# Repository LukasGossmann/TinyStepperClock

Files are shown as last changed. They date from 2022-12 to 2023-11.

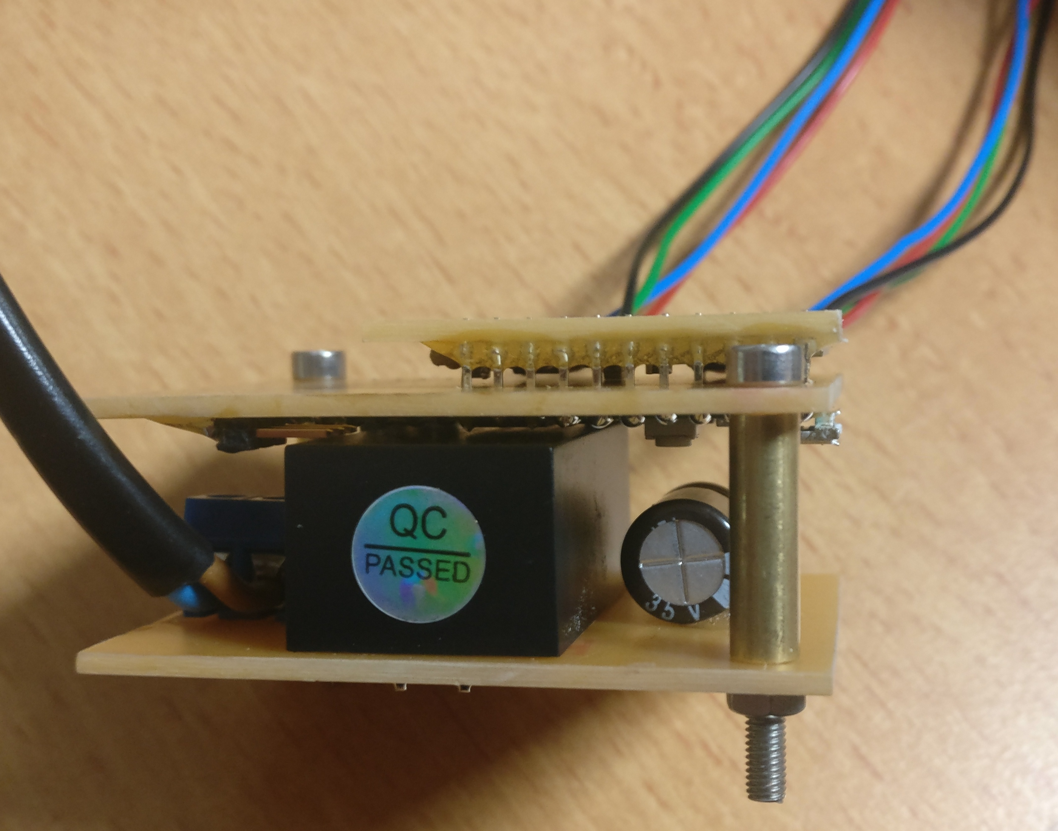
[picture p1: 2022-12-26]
Pictures/Complete_stack.png

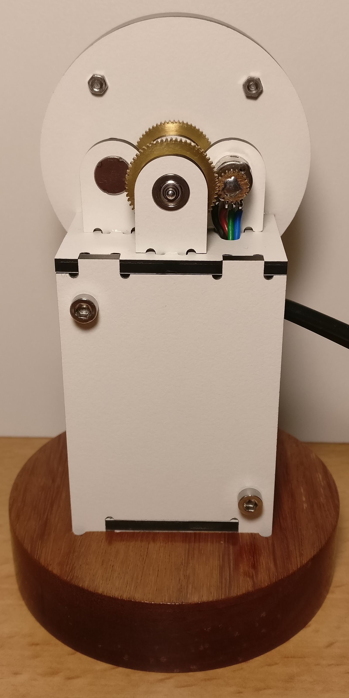
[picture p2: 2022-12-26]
Pictures/Back.png

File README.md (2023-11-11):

<p align="center">
Front view of the clock
</p>

**Description:**  
Tiny stepper motor based clock (including base, L=80mm, W=80mm, H=127mm)  
The clock face is 50mm in diameter with a 5mm wide clear / slightly opaque ring around it for a total diameter of 60mm.  
Behind the clock face is an LED ring with 12 WS2812 LEDs that light up every hour and play a short animation.  
The stepper motors used in this clock are very weak so a lot of care need to be taken to align the shafts properly and for the gears to be running as true as possible on the shafts.  
Each stepper motor has 20 fullsteps per revolution which with a gear reduction of 3:1 gives 60 steps per revolution.  
The minute hand takes a step every minute while the hour hand takes a step every 12 minutes.  
Since this is the tiny version that implies the existence of a bigger stepper motor based clock.
The bigger version can be found here: [StepperClock](https://github.com/LukasGossmann/StepperClock)  
**Waring:** The clock is mains powered and there are a few somewhat exposed live traces / metal contacts so build and use at your own risk.

**Building:**  
Create all parts needed as shown in the FreeCAD drawing.  
Assemble as shown on the pictures and in the FreeCAD drawing.  
A lot of care needs to be taken to be as precise as possible as there isn't much room for tolerance in this design due to the weak motors and tiny gears.  
Also a lot of parts are press fit together (bearings in holders, motors in holders, clock face in clear ring, clear ring on LED ring, etc.) so make sure to adjust the design to fit the expacted tolerances of your manufacturing process and the parts you bought.
Note that one of the stepper motors is wired in the opposite direction so that the same step sequence can be used to drive them.  
If the motors are turning in the wrong direction or both motors were wired the same on accident the code allows for inverting the motor direction as well.
When attaching the clock hands to the shaft the clock needs to be powered on (preferably through usb).  
That way the stepper motors align with one of their magnetic steps which ensures that the hands can properly point to all positions they need to.
Align the clock hands with the 12 o'clock position and solder them in place.

**Tools:**
- **CNC machine** or other way to create parts from a piece of flat material as well as for engraving the clock face.
- **FDM or SLA printer** to create the spacer and the clear ring.
- Depending on the parts you can get and the need to modify them a **lathe** is very useful.
- Soldering iron, screwdrivers, etc.

**Stepper motors:**  
20 steps per rev  
3.3V @ 80mA per coil (gets slightly warm)  
Does not like having both coils energized at the same time, gets pretty hot and doesn't step well  
Diameter: 8mm  
Length: 9.2mm  
Gear (from factory): 10 teeth 0.2 module? (2.3mm diameter)  
Can be found from multiple sellers in china for very cheap (AliExpress)

**Stepper driver:**  
DRV8833 without current limiting (3.3V straight through)  
On a breakout board just soldered onto carrier PCB

**Clock hands:**  
Need to be made of a material that can be soldered to so they can be attached to the shafts.  
CNC milling them from some leftover PCB material works great.

**Power supply:**  
The Pi Pico is powered from a 230V to 5V mains power supply "brick" made by Hi-Link which can supply 600mA.  
To power the stepper drivers the 3.3V output of the Pi Pico is used. 
The stepper motors together draw around 160mA at 3.3V with only one of their coils being active at a time.

**Needed parts (mechanical):**
- 2x 60 tooth gear, 1.4mm thick, 0.3 module
    - one with 4mm hole and one with 2mm hole for the shaft
- 2x 20 tooth gear, 1.4mm thick, 0.3 module
    - with 2.3mm hole to fit onto factory gear of the stepper motor
- 2x Bearing 8mm OD, 4mm ID, 3mm thick
- 1x Bearing 7.3mm OD, 2mm ID, 3mm thick
    - 7mm OD bearings are also available, pick whatever is cheaper and modify the bearing holder design to fit your needs
- 3mm thick material for the frame parts (I used Resopal)
- Brass tube 4mm OD, 2mm ID (shaft for the hour hand)
- Brass tube 5mm OD, 3mm ID (used as spacers for the stacked PCBs)
- Brass rod 2mm (shaft for the minute hand)
- Various M2 and M3 screws, nuts and washers
- A block of wood or other material to make a base for the clock

**Needed parts (electrical):**
- 2x Stepper motor
    - order more than that because they tend to arrive broken (coil wires ripped off)
- 1x Raspberry Pi Pico without headers
- 1x 5V PSU (Hi-Link HLK-PM01 or pin and size compatible)
- 1x WS2812 LED ring with 12 LEDS (~50mm OD)
    - 8 LED version (~32mm OD) should work too with a modified spacer and a few code changes
- 1x Diode (shotkey or any other type, 1N4007 works just fine)
- 1x Capacitor (At least 5V rating, around 470µF works fine)
- 1x 2.54mm 2 pin screw terminal
- Some 2.54mm pin headers
- Thin wires
- The PCBs from the KiCAD project

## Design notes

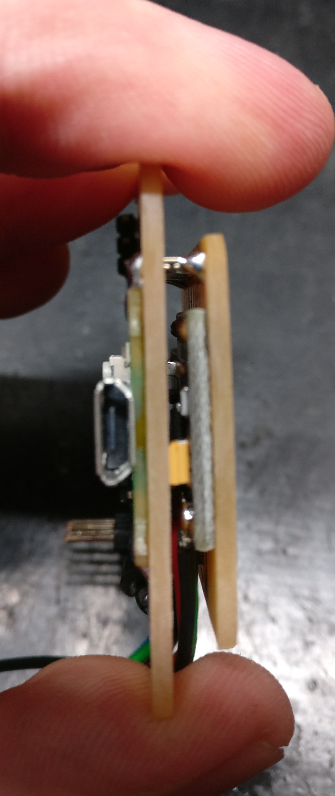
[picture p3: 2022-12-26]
Pictures/Pico_Stepper_driver_stack.png

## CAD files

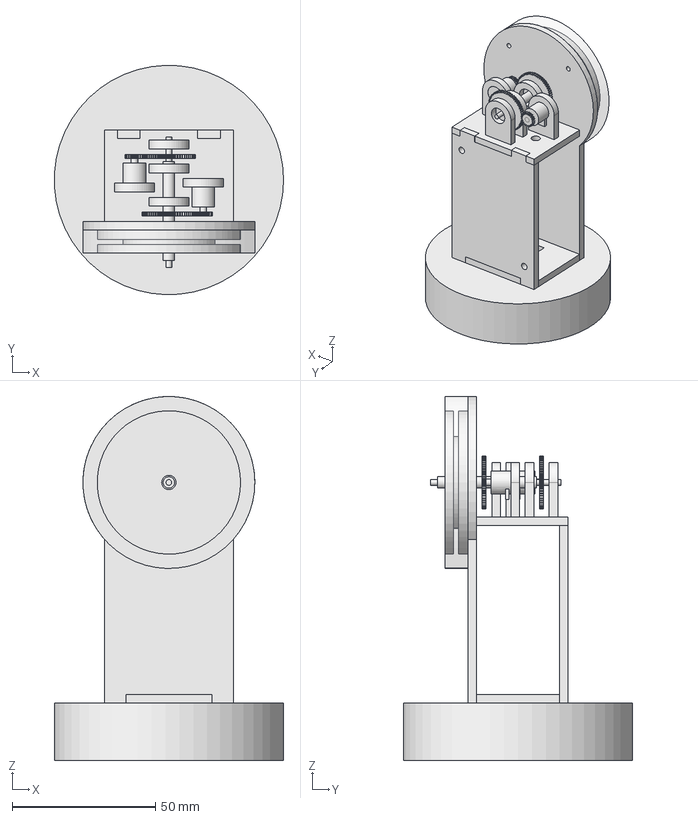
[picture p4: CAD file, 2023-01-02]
FreeCAD/TinyStepperClock.FCStd
79.9 x 80.0 x 127.0 mm
MinuteShaft
HourShaft
MinuteGear
HourGear
HourMotor
MinuteMotor
HourMotorHolder
MinuteMotorHolder
MinuteShaftBearingHolder
HourShaftFrontBearingHolder
HourShaftBackBearingHolder
BasePlate
DialPlate
FrontPlate
BackPlate
BottomPlate
ClearRing
LedRing
Spacer
StandPlate

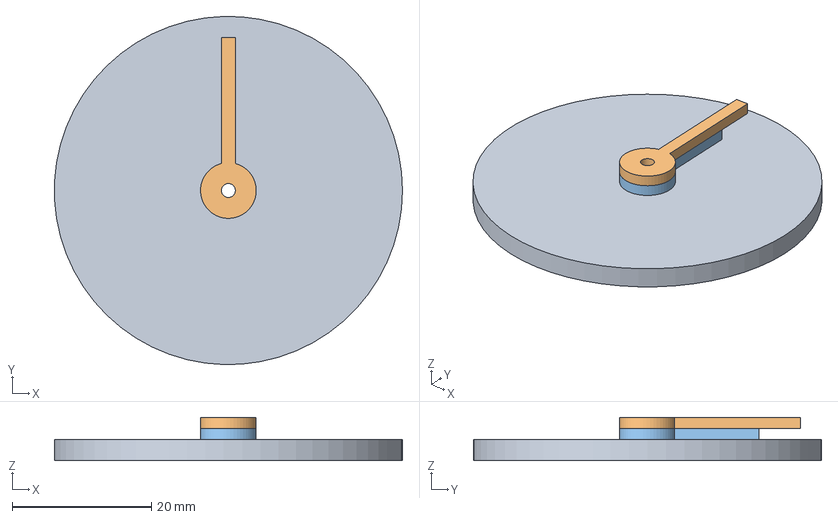
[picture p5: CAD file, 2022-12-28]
FreeCAD/ClockFace.FCStd
50.0 x 50.0 x 6.20 mm
DialPlate
MinuteHand
HourHand

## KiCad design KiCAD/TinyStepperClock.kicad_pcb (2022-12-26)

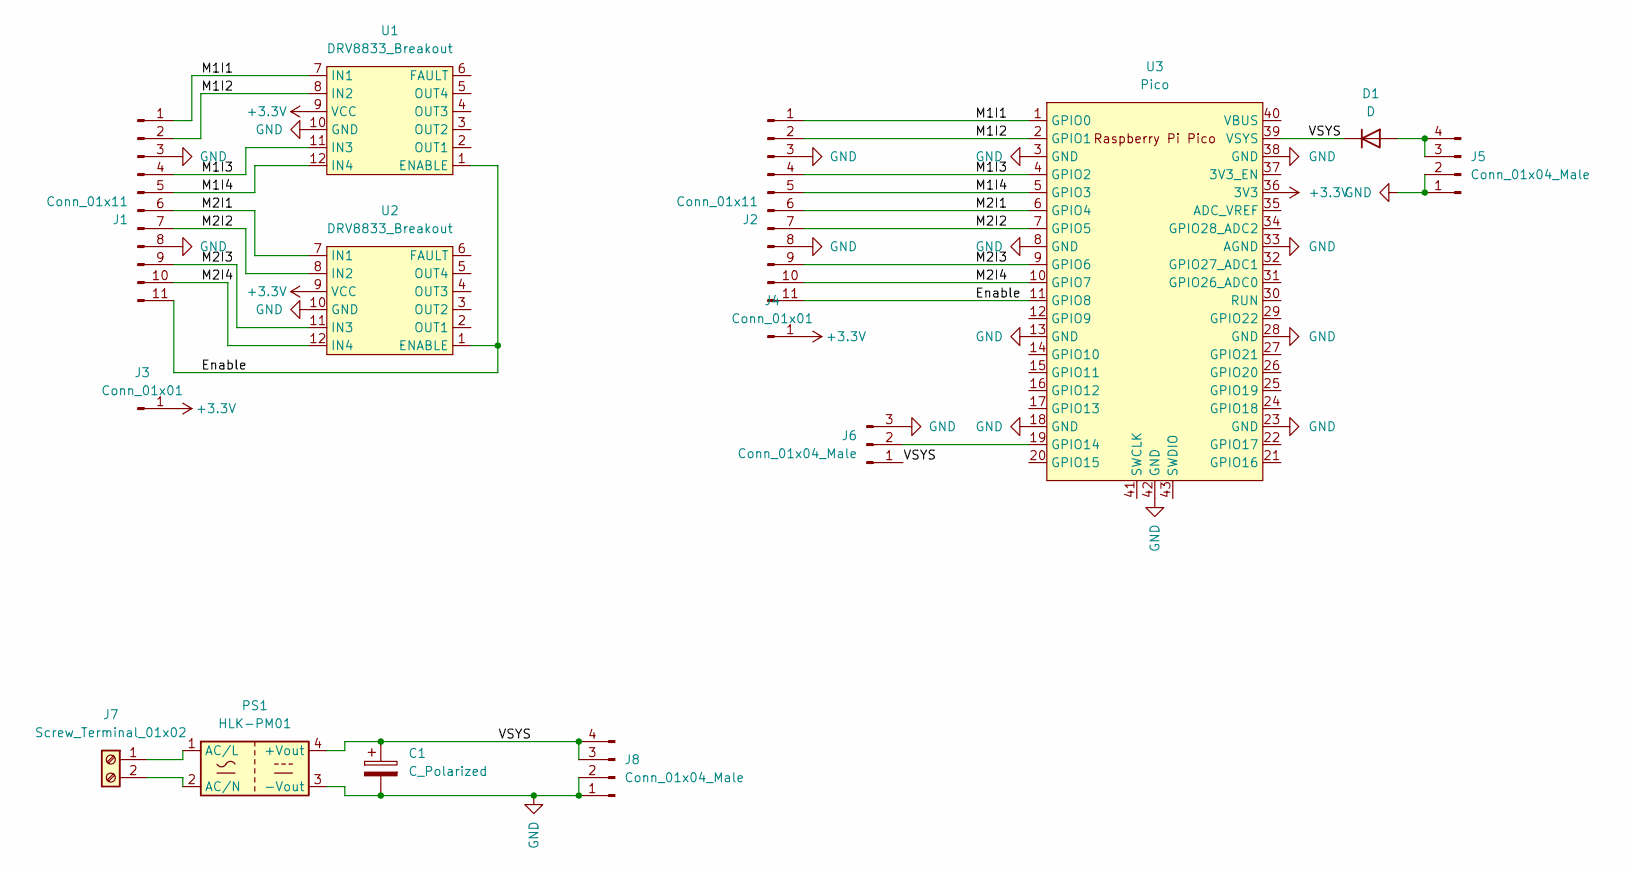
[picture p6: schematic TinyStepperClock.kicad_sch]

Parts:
C1: C_Polarized; CP_Radial_D10.0mm_P5.00mm_P7.50mm
D1: D; D_DO-15_P12.70mm_Horizontal
J1, J2: Conn_01x11; PinHeader_1x11_P2.54mm_Vertical
J3, J4: Conn_01x01; PinHeader_1x01_P2.54mm_Vertical
J5: Conn_01x04_Male; PinHeader_1x04_P2.54mm_Vertical
J6: Conn_01x04_Male; PinHeader_1x03_P2.54mm_Horizontal
J7: Screw_Terminal_01x02; TerminalBlock_Phoenix_MKDS-1,5-2-5.08_1x02_P5.08mm_Horizont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
J8: Conn_01x04_Male; PinSocket_1x04_P2.54mm_Vertical
PS1: HLK-PM01; Converter_ACDC_HiLink_HLK-PMxx
U1, U2: DRV8833_Breakout
U3: Pico; RPi_Pico_SMD_TH

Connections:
+3.3V: J3.1, J4.1, U1.9 (VCC), U2.9 (VCC), U3.36 (3V3)
/Enable: J1.11, J2.11, U1.1 (ENABLE), U2.1 (ENABLE), U3.11 (GPIO8)
/M1I1: J1.1, J2.1, U1.7 (IN1), U3.1 (GPIO0)
/M1I2: J1.2, J2.2, U1.8 (IN2), U3.2 (GPIO1)
/M1I3: J1.4, J2.4, U1.11 (IN3), U3.4 (GPIO2)
/M1I4: J1.5, J2.5, U1.12 (IN4), U3.5 (GPIO3)
/M2I1: J1.6, J2.6, U2.7 (IN1), U3.6 (GPIO4)
/M2I2: J1.7, J2.7, U2.8 (IN2), U3.7 (GPIO5)
/M2I3: J1.9, J2.9, U2.11 (IN3), U3.9 (GPIO6)
/M2I4: J1.10, J2.10, U2.12 (IN4), U3.10 (GPIO7)
/VSYS: C1.1, D1.1 (K), J6.1, J8.3, J8.4, PS1.4 (+Vout), U3.39 (VSYS)
GND: C1.2, J1.3, J1.8, J2.3, J2.8, J5.1, J5.2, J6.3, J8.1, J8.2, PS1.3 (-Vout), U1.10 (GND), U2.10 (GND), U3.3 (GND), U3.8 (GND), U3.13 (GND), U3.18 (GND), U3.23 (GND), U3.28 (GND), U3.33 (AGND), U3.38 (GND), U3.42 (GND)
unnamed: D1.2 (A), J5.3, J5.4
unnamed: J6.2, U3.19 (GPIO14)
unnamed: J7.1, PS1.1 (AC/L)
unnamed: J7.2, PS1.2 (AC/N)

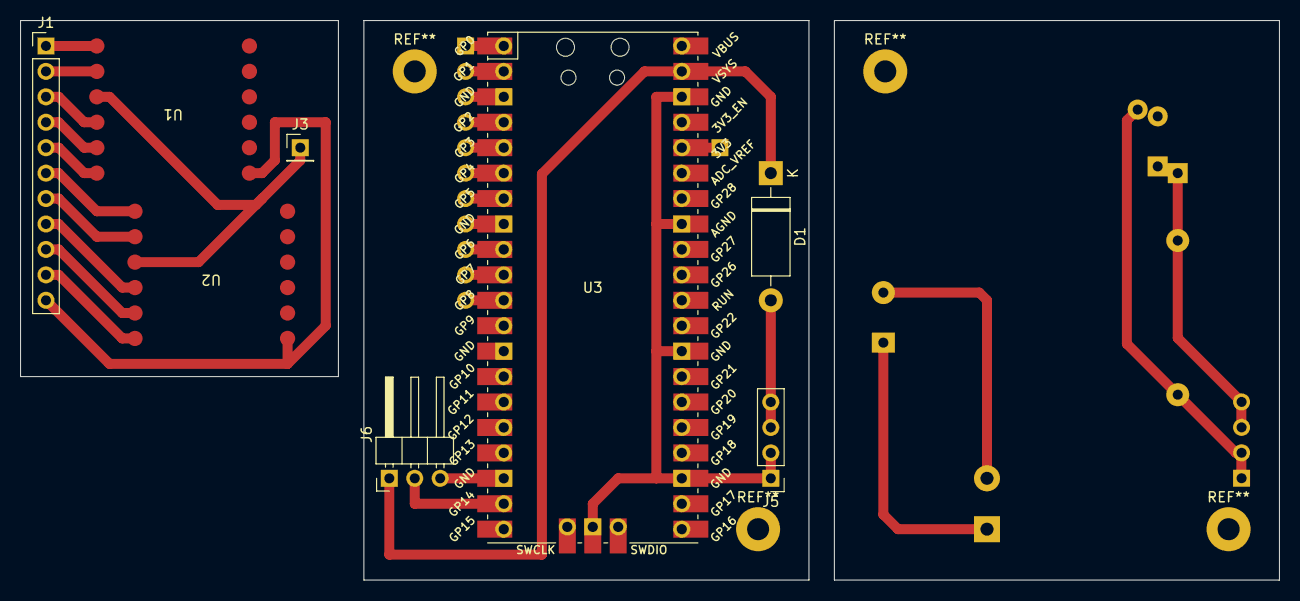
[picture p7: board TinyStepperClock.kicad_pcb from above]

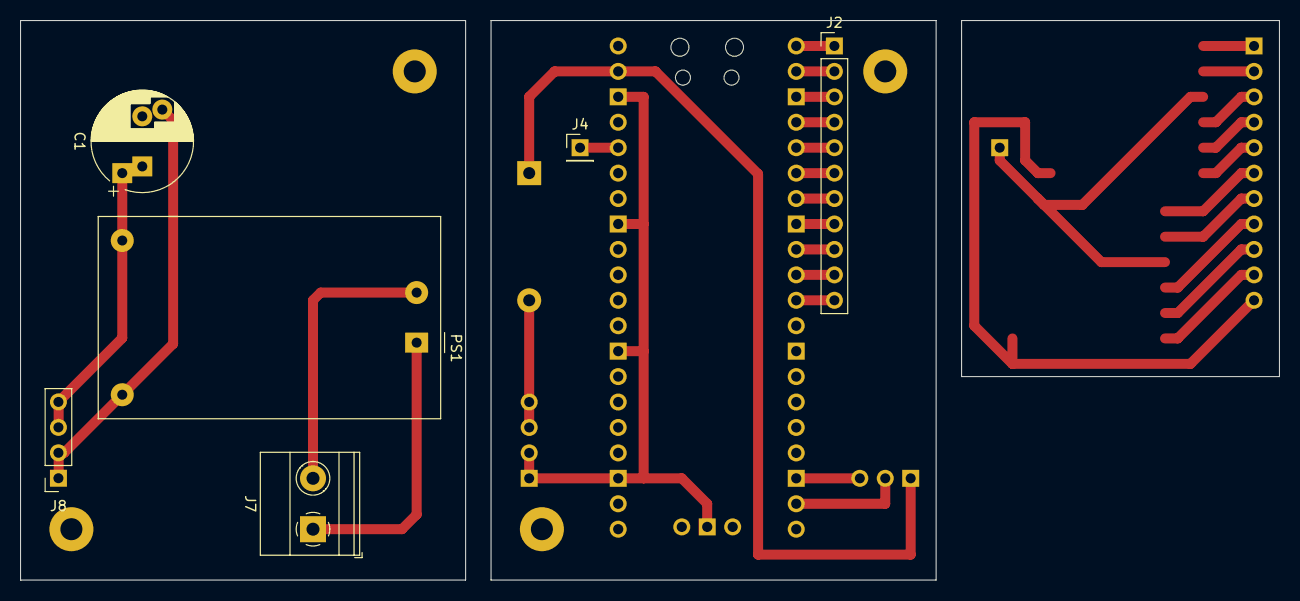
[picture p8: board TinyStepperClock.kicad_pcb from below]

Board: 2 copper layers, 125.7 x 55.9 mm, 14 parts (6 on the bottom side), 16 nets.

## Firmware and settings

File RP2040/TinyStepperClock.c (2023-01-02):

#include <stdio.h>

#include "pico/stdlib.h"

// For scb_hw so we can enable deep sleep
#include "hardware/structs/scb.h"

// For __wfi() function
#include "hardware/sync.h"

#include "PWM.h"
#include "Stepper.h"
#include "RTC.h"
#include "WS2812.h"

/// @brief Handles the usb power detection gpio pin going high.
/// @param gpio The gpio pin that caused the interrupt.
/// @param event_mask The type of interrupt that occured
void usbPowerDetectionHandler(uint gpio, uint32_t event_mask)
{
    if (gpio == 24 && event_mask == GPIO_IRQ_EDGE_RISE)
    {
        // Show that we are awake
        gpio_put(25, true);

        // Disable IRQ for rising edge
        gpio_set_irq_enabled(24, GPIO_IRQ_EDGE_RISE, false);

        // Disable sleep on exit of IRQ hanlder
        scb_hw->scr &= ~M0PLUS_SCR_SLEEPONEXIT_BITS;
    }
}

/// @brief Puts the current core to sleep until gpio pin 24 (usb power detection) goes high.
void goToSleep()
{
    // Enable IRQ for rising edge of usb power
    gpio_set_irq_enabled_with_callback(24, GPIO_IRQ_EDGE_RISE, true, usbPowerDetectionHandler);

    // Turn off all clocks when in sleep mode except for RTC
    // TODO: Check which other clocks need to keep running
    // clocks_hw->sleep_en0 = CLOCKS_SLEEP_EN0_CLK_RTC_RTC_BITS;
    // clocks_hw->sleep_en1 = 0x0;

    // Show that we went to sleep
    gpio_put(25, false);

    // Enable sleep and automatic sleep on exit from irq handler
    scb_hw->scr |= (M0PLUS_SCR_SLEEPDEEP_BITS | M0PLUS_SCR_SLEEPONEXIT_BITS);

    // Go to sleep
    __wfi();
}

/// @brief Reads a line from stdin. Aborts when the virtual serial console gets disconnected.
/// @param buffer The buffer to write the data into.
/// @param sizeOfBuffer The size of the buffer.
/// @return Number of chars read or zero when serial console got disconnected.
uint32_t readLine(char *buffer, uint32_t sizeOfBuffer)
{
    uint32_t index = 0;

    bool powerConnected = false;
    while (powerConnected = gpio_get(24) && index < sizeOfBuffer)
    {
        int c = getchar_timeout_us(1000000); // 1s

        if (c == PICO_ERROR_TIMEOUT)
            continue;

        if (c == '\n' || c == '\r')
        {
            putchar(c);
            break;
        }

        // Only printable ascii
        if (c < ' ' || c > '~')
            continue;

        putchar_raw(c);
        buffer[index++] = c;
    }

    // If power got disconnected before receiving a complete line return zero
    if (!powerConnected)
        return 0;

    return index;
}

/// @brief Converts chars 0 to 9 to an integer.
/// @param c The char to convert.
/// @param number The result of the converion.
/// @return true when the character was between 0 to 9, otherwise false.
bool convertCharToNumber(char c, uint32_t *number)
{
    if (c >= '0' && c <= '9')
    {
        *number = c - '0';
        return true;
    }

    return false;
}

/// @brief Parses a datetime with the given format dd.mm.yy hh:mm
/// @param buffer The buffer containing the string to parse.
/// @param sizeofBuffer The size of the buffer.
/// @param datetime The parsed date time.
/// @return true when the date time was parsed successfully, otherwise false
bool parseDateTime(char *buffer, uint32_t sizeofBuffer, datetime_t *datetime)
{
    if (sizeofBuffer != 14)
    {
        printf("Invalid length: %d\n", sizeofBuffer);
        return false;
    }

    uint32_t digit = 0;
    // Day
    if (!convertCharToNumber(buffer[0], &digit))
    {
        printf("Invalid char (day digit 1): %c\n", buffer[0]);
        return false;
    }
    datetime->day = digit;

    if (!convertCharToNumber(buffer[1], &digit))
    {
        printf("Invalid char (day digit 2): %c\n", buffer[1]);
        return false;
    }
    datetime->day = ((datetime->day * 10) + digit);

    if (buffer[2] != '.')
    {
        printf("Invalid char (day month seperator): %c\n", buffer[2]);
        return false;
    }

    // Month
    if (!convertCharToNumber(buffer[3], &digit))
    {
        printf("Invalid char (month digit 1): %c\n", buffer[3]);
        return false;
    }
    datetime->month = digit;

    if (!convertCharToNumber(buffer[4], &digit))
    {
        printf("Invalid char (month digit 2): %c\n", buffer[4]);
        return false;
    }
    datetime->month = ((datetime->month * 10) + digit);

    if (buffer[5] != '.')
    {
        printf("Invalid char (month year seperator): %c\n", buffer[5]);
        return false;
    }

    // Year
    if (!convertCharToNumber(buffer[6], &digit))
    {
        printf("Invalid char (year digit 1): %c\n", buffer[6]);
        return false;
    }
    datetime->year = digit;

    if (!convertCharToNumber(buffer[7], &digit))
    {
        printf("Invalid char (year digit 2): %c\n", buffer[7]);
        return false;
    }
    datetime->year = (2000 + ((datetime->year * 10) + digit));

    if (buffer[8] != ' ')
    {
        printf("Invalid char (year hour seperator): %c\n", buffer[8]);
        return false;
    }

    // Hour
    if (!convertCharToNumber(buffer[9], &digit))
    {
        printf("Invalid char (hour digit 1): %c\n", buffer[9]);
        return false;
    }
    datetime->hour = digit;

    if (!convertCharToNumber(buffer[10], &digit))
    {
        printf("Invalid char (hour digit 2): %c\n", buffer[10]);
        return false;
    }
    datetime->hour = ((datetime->hour * 10) + digit);

    if (datetime->hour > 23)
    {
        printf("Hour out of range (0-23): %02d", datetime->hour);
        return false;
    }

    if (buffer[11] != ':')
    {
        printf("Invalid char (hour minute seperator): %c\n", buffer[11]);
        return false;
    }

    // Minute
    if (!convertCharToNumber(buffer[12], &digit))
    {
        printf("Invalid char (minute digit 1): %c\n", buffer[12]);
        return false;
    }
    datetime->min = digit;

    if (!convertCharToNumber(buffer[13], &digit))
    {
        printf("Invalid char (minute digit 2): %c\n", buffer[12]);
        return false;
    }
    datetime->min = ((datetime->min * 10) + digit);

    if (datetime->min > 59)
    {
        printf("Minute out of range (0-59): %02d", datetime->min);
        return false;
    }

    return true;
}

/// @brief Parses a string containing a 2 digit hour (00-23)
/// @param buffer The buffer containing the string to parse.
/// @param sizeofBuffer The size of the buffer.
/// @param hour The parsed hour.
/// @return true when the hour was parsed successfully, otherwise false
bool parseHour(char *buffer, uint32_t sizeofBuffer, uint8_t *hour)
{
    if (sizeofBuffer != 2)
    {
        printf("Invalid length: %d\n", sizeofBuffer);
        return false;
    }

    uint32_t digit = 0;
    if (!convertCharToNumber(buffer[0], &digit))
    {
        printf("Invalid char (hour digit 1): %c\n", buffer[0]);
        return false;
    }
    *hour = digit;

    if (!convertCharToNumber(buffer[1], &digit))
    {
        printf("Invalid char (hour digit 2): %c\n", buffer[1]);
        return false;
    }

    *hour = ((*hour * 10) + digit);

    if (*hour > 23)
    {
        printf("Hour out of range (0-23): %i", *hour);
        return false;
    }

    return true;
}

/// @brief Parses a string containing a boolean (yYnN)
/// @param buffer The buffer containing the string to parse.
/// @param sizeofBuffer The size of the buffer.
/// @param value The parsed boolean.
/// @return true when the boolean was parsed successfully, otherwise false
bool parseBool(char *buffer, uint32_t sizeofBuffer, bool *value)
{
    if (sizeofBuffer != 1)
    {
        printf("Invalid length: %d\n", sizeofBuffer);
        return false;
    }

    if (buffer[0] == 'Y' || buffer[0] == 'y')
    {
        *value = true;
        return true;
    }

    if (buffer[0] == 'N' || buffer[0] == 'n')
    {
        *value = false;
        return true;
    }

    return false;
}

/// @brief Manually home the given stepper motor by typing + or - on the virtual serial console.
/// @param stepper The stepper motor to home.
/// @return true when the motor was homed or false when the process was aborted.
bool manualHomeStepper(struct stepper *stepper)
{
    // Move motor a step and break when enter is pressed
    bool powerConnected;
    while (powerConnected = gpio_get(24))
    {
        int c = getchar_timeout_us(1000000); // 1s

        if (c == PICO_ERROR_TIMEOUT)
            continue;

        if (c == '\n' || c == '\r')
            break;

        if (c == '+')
            stepperStep(stepper, false);
        else if (c == '-')
            stepperStep(stepper, true);
    }

    return powerConnected;
}

int main()
{
    // Init driver enable pin
    gpio_init(8);
    gpio_set_dir(8, true);
    gpio_put(8, false); // Disable driver

    // Init step generator
    initStepper(&hourStepper);
    initStepper(&minuteStepper);
    gpio_put(8, true); // Enable stepper drivers

    // USB power detection gpio
    gpio_init(24);
    gpio_set_dir(24, false);

    // Onboard led
    gpio_init(25);
    gpio_set_dir(25, true);
    gpio_put(25, true);

    ws2812_init();

    // If usb power isnt connected to to sleep
    if (!gpio_get(24))
        goToSleep();

    // Either we awoke from sleep or power was connected already
    while (true)
    {
        // Show that we are awake
        gpio_put(25, true);

        // Wait 500ms before attempting to do anything
        sleep_ms(500);

        // While power is connected to the usb port try to init stdio through usb
        bool powerConnected = false;
        while (powerConnected = gpio_get(24))
        {
            if (stdio_usb_init())
                break;

            sleep_ms(1000);
        }
        if (!powerConnected)
            goto endOfLoop;

        // Wait until something has connected to the virtual serial port
        while (powerConnected = gpio_get(24))
        {
            if (stdio_usb_connected())
                break;

            sleep_ms(1000);
        }
        if (!powerConnected)
            goto endOfLoop;

        // Display start message
        puts("TinyStepperClock V1.0 Press enter to continue.");

        // Wait until enter is pressed
        while (powerConnected = gpio_get(24))
        {
            int c = getchar_timeout_us(1000000); // 1s

            if (c == PICO_ERROR_TIMEOUT)
                continue;

            if (c == '\n' || c == '\r')
                break;
        }
        if (!powerConnected)
            goto endOfLoop;

        char buffer[128];

        puts("Enable hourly animations (y,n):");
        while (powerConnected = gpio_get(24))
        {
            uint32_t numberOfCharsRead = readLine(buffer, count_of(buffer));

            // If nothing has been read either the power has been disconnected or enter was pressed immediately
            if (numberOfCharsRead == 0)
                continue;

            bool success = parseBool(buffer, numberOfCharsRead, &enableHourlyAnimation);
            if (success)
            {
                printf("Animations enabled: %s\n", enableHourlyAnimation ? "Y" : "N");
                break;
            }

            puts("Invalid input!");
        }
        if (!powerConnected)
            goto endOfLoop;

        if (enableHourlyAnimation)
        {
            puts("Enter animation start hour (00-23):");
            while (powerConnected = gpio_get(24))
            {
                uint32_t numberOfCharsRead = readLine(buffer, count_of(buffer));

                // If nothing has been read either the power has been disconnected or enter was pressed immediately
                if (numberOfCharsRead == 0)
                    continue;

                bool success = parseHour(buffer, numberOfCharsRead, &animationStartHour);
                if (success)
                {
                    printf("Got hour: %02d\n", animationStartHour);
                    break;
                }

                puts("Invalid input!");
            }
            if (!powerConnected)
                goto endOfLoop;

            puts("Enter animation end hour (00-23):");
            while (powerConnected = gpio_get(24))
            {
                uint32_t numberOfCharsRead = readLine(buffer, count_of(buffer));

                // If nothing has been read either the power has been disconnected or enter was pressed immediately
                if (numberOfCharsRead == 0)
                    continue;

                bool success = parseHour(buffer, numberOfCharsRead, &animationEndHour);
                if (success)
                {
                    printf("Got hour: %02d\n", animationEndHour);
                    break;
                }

                puts("Invalid input!");
            }
            if (!powerConnected)
                goto endOfLoop;
        }

        // Disable rtc alarm after this point so the clock hands dont move while we are trying to set the clock
        disableRtcAlarm();

        puts("Move hour hand to 12 o'clock position and press enter. + = CW - = CCW");
        powerConnected = manualHomeStepper(&hourStepper);
        if (!powerConnected)
            goto endOfLoop;

        puts("Move minute hand to 12 o'clock position and press enter. + = CW - = CCW");
        powerConnected = manualHomeStepper(&minuteStepper);
        if (!powerConnected)
            goto endOfLoop;

        datetime_t dateAndTime = {};

        // Display prompt for setting the date and time
        puts("Type date and time (dd.mm.yy hh:mm) and press enter.");
        while (powerConnected = gpio_get(24))
        {
            uint32_t numberOfCharsRead = readLine(buffer, count_of(buffer));

            // If nothing has been read either the power has been disconnected or enter was pressed immediately
            if (numberOfCharsRead == 0)
                continue;

            bool success = parseDateTime(buffer, numberOfCharsRead, &dateAndTime);
            if (success)
            {
                printf("Got date and time: %02d.%02d.%d %02d:%02d\n",
                       dateAndTime.day,
                       dateAndTime.month,
                       dateAndTime.year,
                       dateAndTime.hour,
                       dateAndTime.min);
                break;
            }

            puts("Invalid input!");
        }
        if (!powerConnected)
            goto endOfLoop;

        seekClockHands(&dateAndTime);
        rtcInit(&dateAndTime);

        // Wait until power is disconnected before going to sleep to prevent the usb device from disconnecting improperly.
        while (gpio_get(24))
            sleep_ms(500);

    endOfLoop:
        goToSleep();
    }

    return 0;
}

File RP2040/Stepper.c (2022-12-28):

#include "hardware/gpio.h"

#include "Stepper.h"

/*
0: AOUT1
1: AOUT2
2: BOUT1
3: BOUT2

1=mosfet active
0=mostfet inactive
*/

/// @brief Sequence for controling the h-bridge so the stepper motor takes 4 full steps.
const uint32_t stepSequence[] = {0b1000, 0b0010, 0b0100, 0b0001};
const uint32_t stepSequenceLength = count_of(stepSequence);

/// @brief Configuration for a stepper motor
struct stepper
{
    /// @brief Bit mask for the gpio pins used to drive the h-bridge of the stepper.
    /// All used pins need to be consecutive.
    uint32_t gpio_mask;

    /// @brief Number of bits the values of the step sequence need to be shifted by to align with the gpio mask.
    uint32_t gpio_shift;

    /// @brief Initial index of the step sequnce array. Leave at zero.
    uint32_t step_index;
};

/// @brief Configuration for the hour stepper motor.
struct stepper hourStepper = {
    0b00001111,
    0,
    0,
};

/// @brief Configuration for the minute stepper motor.
struct stepper minuteStepper = {
    0b11110000,
    4,
    0,
};

/// @brief Initializes the gpio pins for a stepper motor using the given configuration.
/// @param stepper The stepper motor to configure.
void initStepper(struct stepper *stepper)
{
    gpio_init_mask(stepper->gpio_mask);
    gpio_set_dir_out_masked(stepper->gpio_mask);
    gpio_put_masked(stepper->gpio_mask, stepSequence[0] << stepper->gpio_shift);
}

/// @brief Moves the given stepper motor in the indicated direction.
/// @param stepper The stepper motor to move.
/// @param forward The direction to move the stepper motor.
void stepperStep(struct stepper *stepper, bool forward)
{
    if (forward)
    {
        if (stepper->step_index < stepSequenceLength - 1)
            stepper->step_index++;
        else
            stepper->step_index = 0;
    }
    else
    {
        if (stepper->step_index > 0)
            stepper->step_index--;
        else
            stepper->step_index = stepSequenceLength - 1;
    }

    uint32_t value = stepSequence[stepper->step_index];
    uint32_t shiftedValue = value << stepper->gpio_shift;

    gpio_put_masked(stepper->gpio_mask, shiftedValue);
}

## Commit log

2022-12-28 Lots of cleanup
    [ClockFace.FCStd, DialPlate.FCStd, TinyStepperClock.FCStd]
2023-01-02 Fixed bug where clock hands would move while setting the time and cad model updates
    [TinyStepperClock.FCStd]
2023-02-02 Readded missing update of rtc alarm
    [RTC.c]
